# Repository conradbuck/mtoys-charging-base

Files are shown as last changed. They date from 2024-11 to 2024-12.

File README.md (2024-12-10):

# Magical Toys (magicaltoys.com) Charging PCB

This PCB is meant to be used in tandem with their talking stuffed dinosaur as a charging dock to make recharging the dino easier. It is meant to fit into the 3d printed housing in the 3d-files directory.

The PCB uses an op-amp (U1) and shunt resistor in series with the power connectors on the low side to detect when current is flowing through the trace. When a dino stuffed animal is placed on top of the dock, the barrel plug attached to the center connector supplies power to the stuffed animal. The dino charges at 5V at a nominal current of 1.8A. When 1.8A flows across the shunt resistor, it generates a voltage difference of about 0.2V. The op-amp takes in this voltage measurement and compares its difference to Ground at 0V. The op-amp is set to have a threshold of 0.15V. When a voltage greater than that is supplied, it outputs a logical HIGH and turns on the LED at the other end of the PCB. Hence, the LED is only illuminated when the dino is connected to the dock and charging. The LED automatically turns off when the dino is no longer charging or disconnected from the dock.

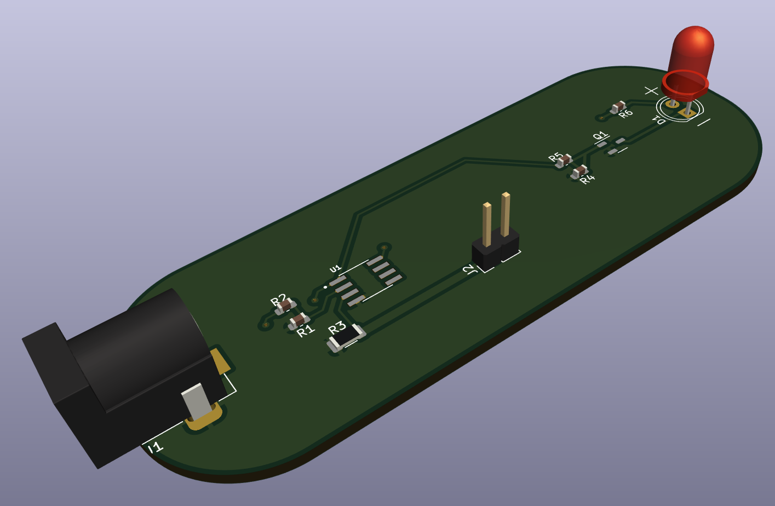
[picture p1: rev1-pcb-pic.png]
Image-of-PCB


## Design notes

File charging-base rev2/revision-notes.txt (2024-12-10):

-add info text to help with assembly
-see if you can get LED placed on baord by JLC
-enlarge holes on PCB for power connector solder point
	-potentially make holes compatible with screw terminal
	-find vertical SMD barrel jack (ask kevin from pamirAI)

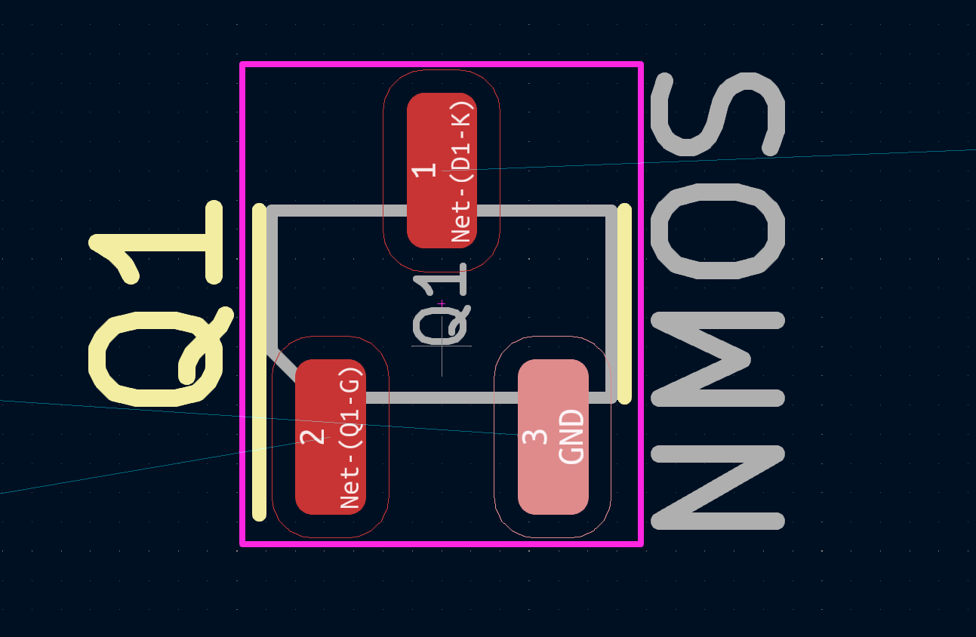
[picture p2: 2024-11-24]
proper-nmos-config.png

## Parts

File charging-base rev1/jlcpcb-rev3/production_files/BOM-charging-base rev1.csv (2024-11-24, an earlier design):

Comment | Designator | Footprint | LCSC
35mOhm | R3 | R_1206_3216Metric | C5185598
10K | R4 | C_0603_1608Metric
PowerToDino | J2 | PinHeader_1x02_P2.54mm_Vertical
1M | R2 | C_0603_1608Metric
Barrel_Jack | J1 | BarrelJack_Horizontal | C136744
LED | D1 | LED_D5.0mm | C883178
220 | R6 | C_0603_1608Metric
10K | R1 | C_0603_1608Metric
10 | R5 | C_0603_1608Metric
LM358_DFN | U1 | DFN-8-1EP_2x2mm_P0.5mm_EP1.05x1.75mm | C9418
NMOS | Q1 | SOT-23-3 | C347475

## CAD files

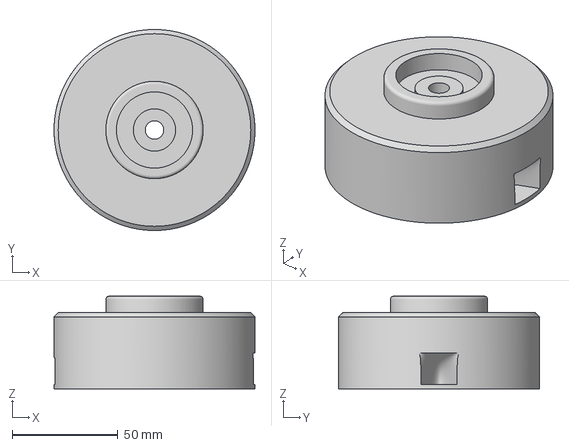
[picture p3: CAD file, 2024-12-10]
3d-files/m-toys charging base top rev3.3mf
95.0 x 95.0 x 43.8 mm

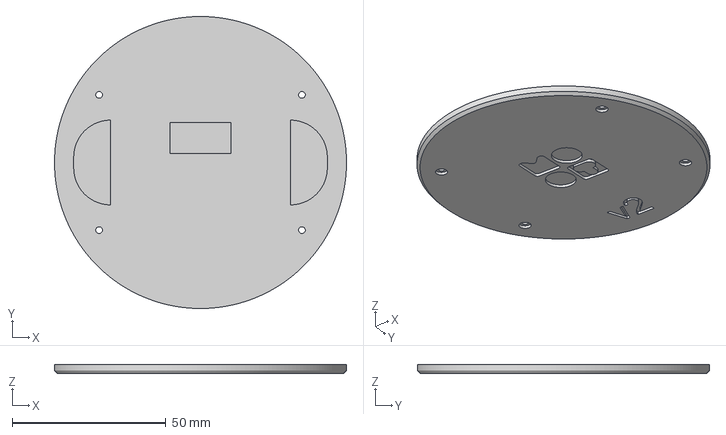
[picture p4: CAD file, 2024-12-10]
3d-files/m-toys charging base bottom lid rev3.3mf
95.0 x 95.0 x 3.02 mm

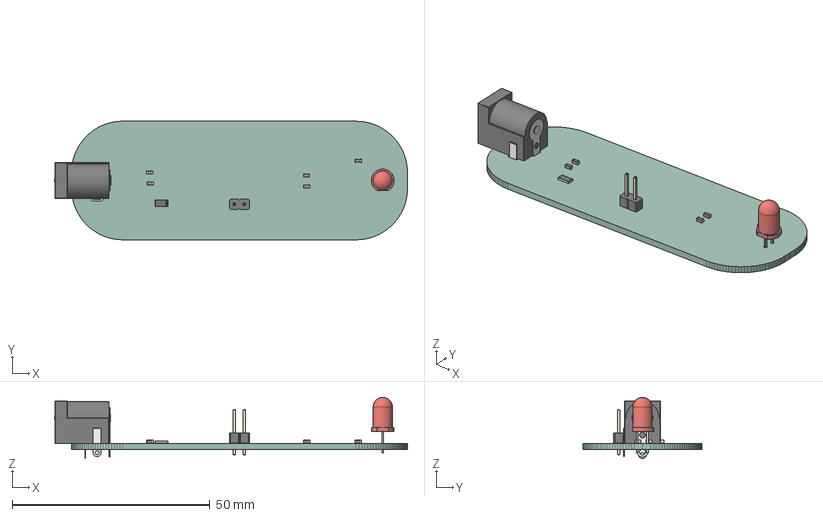
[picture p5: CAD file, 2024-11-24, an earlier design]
charging-base rev1/charging-base rev1.step
89.3 x 30.0 x 15.5 mm
R_1206_3216Metric
C_0603_1608Metric x 5
PinHeader_1x02_P254mm_Vertical
BarrelJack_Horizontal
LED_D5.0mm
charging-base rev1 PCB

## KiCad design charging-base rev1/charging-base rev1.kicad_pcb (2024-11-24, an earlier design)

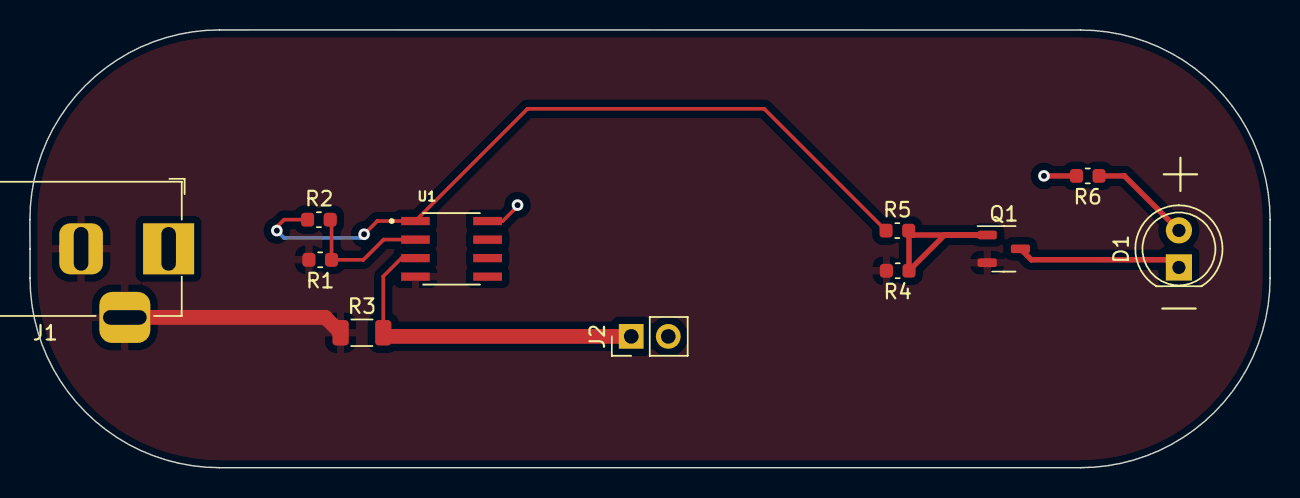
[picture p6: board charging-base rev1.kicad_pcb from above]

Board: 2 copper layers, 85.0 x 30.0 mm, 11 parts (0 on the bottom side), 8 nets.

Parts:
D1: LED; LED_D5.0mm
J1: Barrel_Jack; BarrelJack_Horizontal
J2: PowerToDino; PinHeader_1x02_P2.54mm_Vertical
Q1: NMOS; SOT-23-3
R1, R4: 10K; C_0603_1608Metric
R2: 1M; C_0603_1608Metric
R3: 250mOhm; R_1206_3216Metric
R5: 10; C_0603_1608Metric
R6: 220; C_0603_1608Metric
U1: LM358_DFN; SOIC127P600X175-8N

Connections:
+VDC: J1.1, J2.2, R6.2, U1.8 (V+)
/output-voltage: R2.2, R5.1, U1.1
GND: J1.2, J1.3, Q1.3 (S), R1.2, R3.1, R4.2, U1.4 (V-)
unnamed: D1.2 (A), R6.1
unnamed: D1.1 (K), Q1.1 (D)
unnamed: J2.1, R3.2, U1.3 (+)
unnamed: Q1.2 (G), R4.1, R5.2
unnamed: R1.1, R2.1, U1.2 (-)

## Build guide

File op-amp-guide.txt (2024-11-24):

https://www.allaboutcircuits.com/technical-articles/resistive-current-sensing-low-side-versus-high-side-sensing/

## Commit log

2024-11-24 added blank pcb files
    [charging-base rev1.kicad_pcb, charging-base rev1.kicad_sch]
2024-11-24 added op-amp and nmos to schem
    [charging-base rev1.kicad_pcb, charging-base rev1.kicad_sch]
2024-11-24 added some power questions
    [charging-base rev1.kicad_sch]
2024-11-24 finished rev1 of layout, resistor sensor not yet selected
    [charging-base rev1.kicad_pcb, charging-base rev1.kicad_sch]
2024-11-24 added barrel plug source, changed footprint U1
    [BOM-charging-base rev1.csv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]
2024-11-24 added rev3 manufacturing files
    [BOM-charging-base rev1.csv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]
2024-11-24 added op-amp guide
    [charging-base rev1.step]
2024-11-24 added pic of pcb
2024-12-10 added 3d files and pic to readme
    [m-toys charging base bottom lid rev3.3mf, m-toys charging base top rev3.3mf]
2024-12-10 fixed pic of pcb
